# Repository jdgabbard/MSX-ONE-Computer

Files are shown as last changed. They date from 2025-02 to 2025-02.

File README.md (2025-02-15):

# MSX-ONE Computer

A small, easy to build MSX1 compatible computer.<br>

***See Build Notes file for special instructions!***

Designed as a cheap, and easy to build, MSX1 computer for the US Vintage Computer enthusiast.

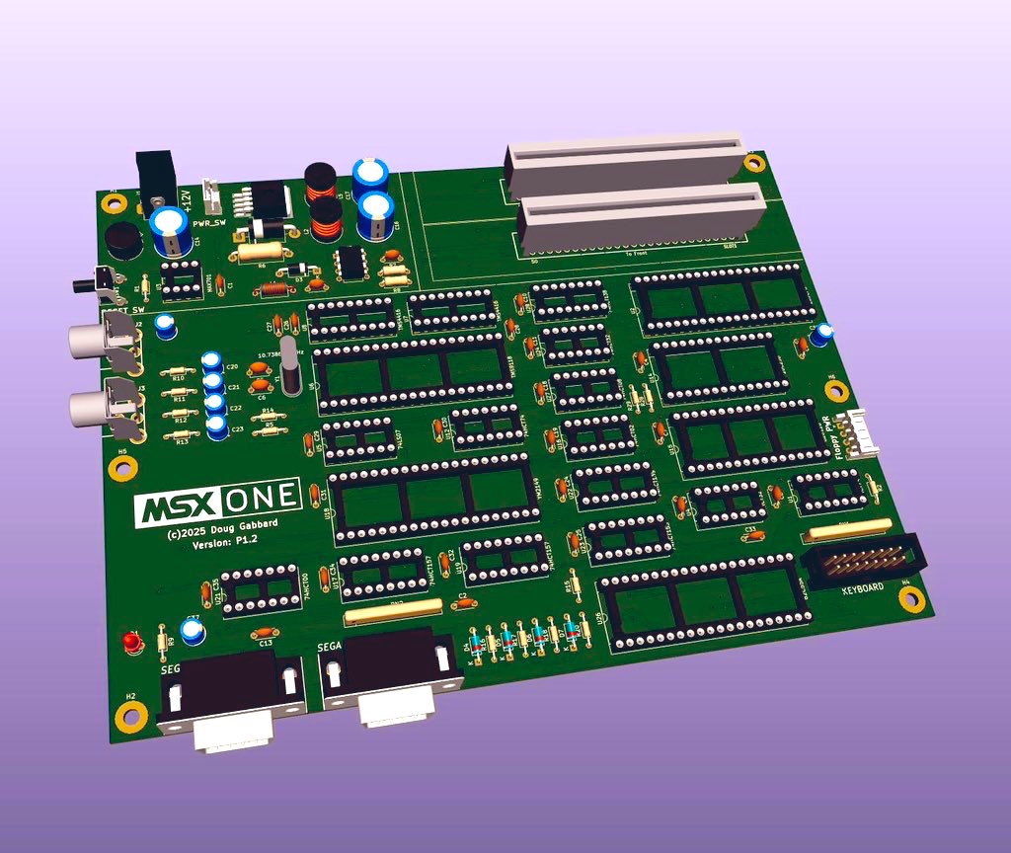
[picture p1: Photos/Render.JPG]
MSXONE


**Features include:**<br><br>
-Small Footprint:
     -Mainboard size: 200mm x 150mm
     -Keyboard size: 200mm x 95mm
-Power-On Reset Supervisor Circuit providing automatic 200ms Reset.
-Flexible power input handles +12v DC to +12v AC power supplies.<br>
-Implements +12v/-12v rails, so Audio Cartridges work correctly.<br>
-2x Sega Gamepad compatible ports, since finding MSX controllers in the US is all but impossible.<br>
-TMS9118 Low Cost alternative does away with numerous DRAM chips, or finicky SRAM circuits, using just two 4bit DRAMs.<br>
-Two Primary Slots available to the user.<br>
-Construction consisting of off the shelf TTL logic, without the need for any programable logic, SPLDs or FPGAs to worry about programming.<br>
-A small form factor, consisting of a PCB approximately the same size as a ZX Spectrum: 200mm x 150mm<br>
-A stackable keyboard (Omega Home Computer Compatible) using cheap tactile switches with an optional cover for aesthetics.<br><br>

**Inspiration**
This computer was heavily inspired by, and borrowing from, both Sergey Kiselev's Omega Home Computer, and the JFF Computer (https://github.com/konkotgit/JFF), as well as the Casio MX-10.<br><br>

I desired a MSX without all the fluff, but with the modularity that the Omega Computer affords.  I wanted a simplified circuit, but with nice options such as power regulation, options for a mechanical power switch, and +12v/-12v rails.  The MSX-ONE gives the casual MSX user just the basics to have a functional yet flexible machine for playing MSX1 games.  And it does this without the need for programmable logic.  The design uses all off the shelf TTL compatible parts, which are still in current production.<br><br>

**Specifications:**<br>
-TMS9118 VDP with 16k DRAM (2x4bit DRAMS)<br>
-32k EEPROM in SLOT0 (BIOS with International Keyboard, Mapper Initializer & BASIC 1.0)<br>
-64K SRAM in SLOT3<br>
-Standard PSG<br>
-International Keyboard<br>
-No Printer Port<br>
-No Cassette Interface<br>
-No Disk Drive<br>
-No Fluff<br>

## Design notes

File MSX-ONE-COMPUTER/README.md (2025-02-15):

# MSX-ONE Mainboard

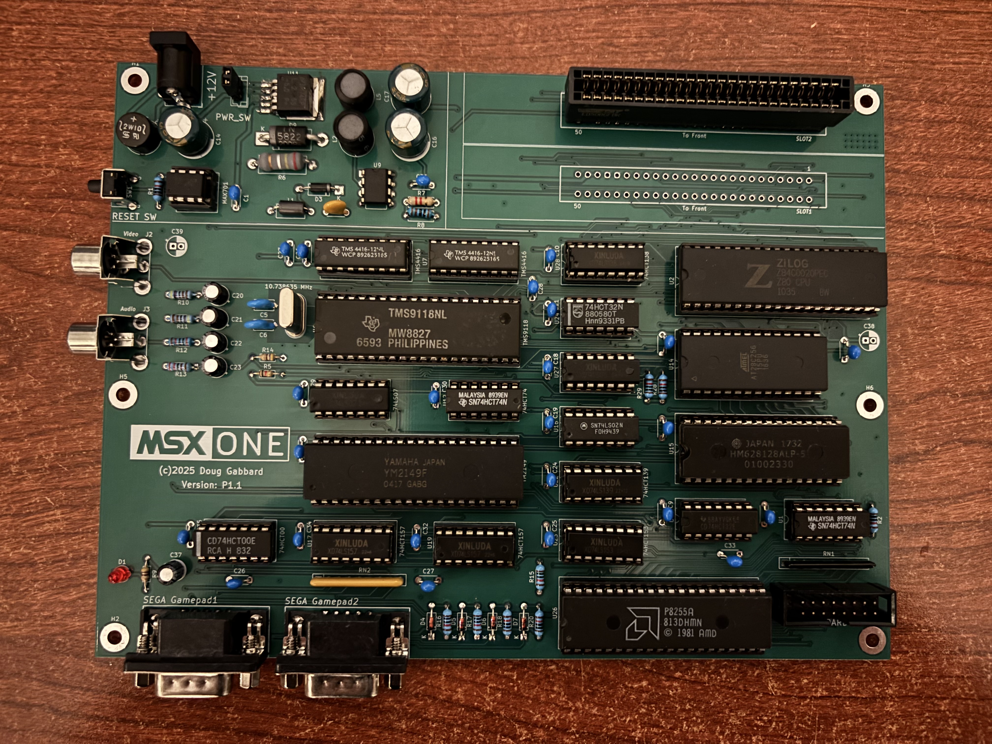
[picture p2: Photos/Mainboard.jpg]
Mainboard


Currently, v1.0 of the Mainboard is untested.  Three insignificant changes were made to the mainboard from version P1.1: the addition of a loading resistor on the -12v circuit, addition of a power connector for external floppy support, and a slight change to page select logic (should have no impact in function).  However, with that in mind, it is at this time untested.  Use of Prototype P1.1 version of the main board is preferable, as it is tested and functional at this time.  This will be changed as soon as I have a chance to order new boards and properly test them, in a few weeks.

#NOTE:
MAX701 has not been used in this circuit, due to sourcing issues.  I have opted to myself use a ATTINY85 with a firmware to automatically reset the system on boot and during reset.

BOM is being developed, along with a list of Digikey and Mouser part numbers.  Stay tuned...

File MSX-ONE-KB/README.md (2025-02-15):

# MSX-ONE Keyboard

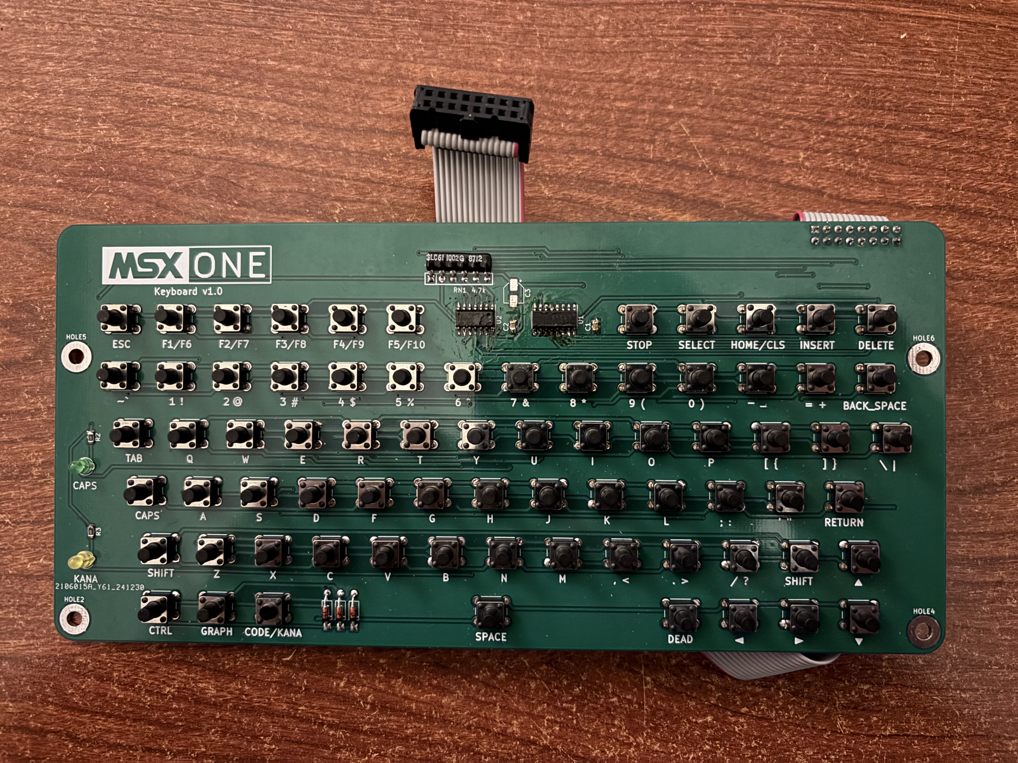
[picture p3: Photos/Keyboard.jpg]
Keyboard


The keyboard circuit is completely working, and stands at vesion 1.0

I will likely add a different board layout using standard 1/4w resistors for the LEDs.

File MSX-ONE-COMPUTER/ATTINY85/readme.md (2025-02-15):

#ATTINY85 Substitute for MAX701

Here are the fuse settings for the ATTINY85, use the Binary supplied in this folder, which provides a time delayed reset of the system during boot, and when reset is pressed.

Low Fuse: E2
High Fuse: D7
Extended Fuse: FF
Lock Bit: FF

ATTINY85 is set to 8mhz internal clock without a lock bit.

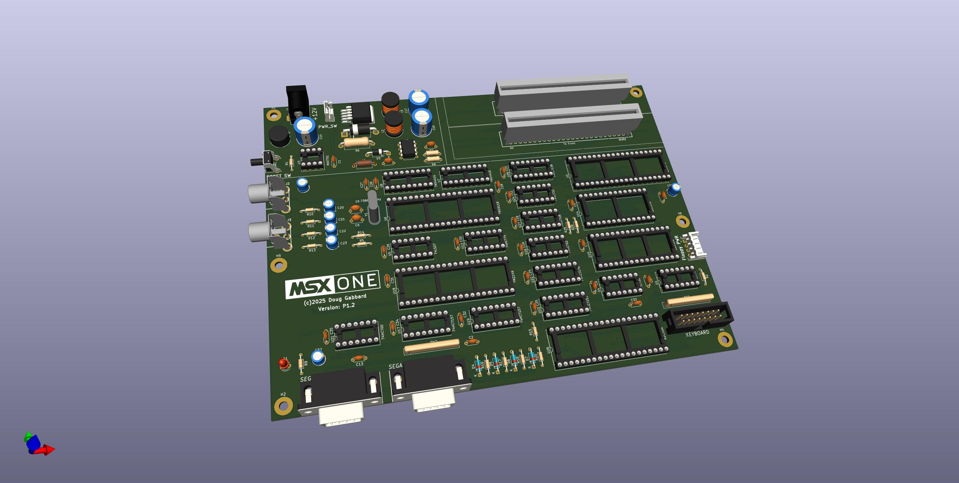
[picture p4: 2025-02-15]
MSX-ONE-COMPUTER/Kicad/MSX-ONE.jpg

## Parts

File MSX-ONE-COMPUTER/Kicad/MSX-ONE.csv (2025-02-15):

Source: | C:\Users\jdgab\Documents\KiCad\MSX-ONE\MSX-ONE-COMPUTER\Kicad\MSX-ONE.kicad_sch
Date: | 1/27/2025 6:11:55 PM
Tool: | Eeschema (6.0.7)
Generator: | C:\Program Files\KiCad\6.0\bin\scripting\plugins/bom_csv_grouped_by_value.py
Component Count: | 110
Individual Components:
Item | Qty | Reference(s) | Value | LibPart | Footprint | Datasheet
 |  | C1 | 100nF | Device:C | Capacitor_THT:C_Disc_D4.3mm_W1.9mm_P5.00mm | ~
 |  | C2 | 100nF | Device:C | Capacitor_THT:C_Disc_D4.3mm_W1.9mm_P5.00mm | ~
 |  | C3 | 100nF | Device:C | Capacitor_THT:C_Disc_D4.3mm_W1.9mm_P5.00mm | ~
 |  | C4 | 100nF | Device:C | Capacitor_THT:C_Disc_D4.3mm_W1.9mm_P5.00mm | ~
 |  | C5 | 27pF | Device:C | Capacitor_THT:C_Disc_D4.7mm_W2.5mm_P5.00mm | ~
 |  | C6 | 27pF | Device:C | Capacitor_THT:C_Disc_D4.7mm_W2.5mm_P5.00mm | ~
 |  | C7 | 100nF | Device:C | Capacitor_THT:C_Disc_D4.3mm_W1.9mm_P5.00mm | ~
 |  | C8 | 100nF | Device:C | Capacitor_THT:C_Disc_D4.3mm_W1.9mm_P5.00mm | ~
 |  | C9 | 100nF | Device:C | Capacitor_THT:C_Disc_D4.3mm_W1.9mm_P5.00mm | ~
 |  | C10 | 100nF | Device:C | Capacitor_THT:C_Disc_D4.3mm_W1.9mm_P5.00mm | ~
 |  | C11 | 100nF | Device:C | Capacitor_THT:C_Disc_D4.3mm_W1.9mm_P5.00mm | ~
 |  | C12 | 1.5nF | Device:C | Capacitor_THT:C_Disc_D4.3mm_W1.9mm_P5.00mm | ~
 |  | C14 | 220uF | Device:C_Polarized_Small | Capacitor_THT:CP_Radial_D10.0mm_P5.00mm | ~
 |  | C16 | 470uF | Device:C_Polarized | Capacitor_THT:CP_Radial_D10.0mm_P5.00mm | ~
 |  | C17 | 470uF | Device:C_Polarized | Capacitor_THT:CP_Radial_D10.0mm_P5.00mm | ~
 |  | C18 | 100nF | Device:C | Capacitor_THT:C_Disc_D4.3mm_W1.9mm_P5.00mm | ~
 |  | C19 | 100nF | Device:C | Capacitor_THT:C_Disc_D4.3mm_W1.9mm_P5.00mm | ~
 |  | C20 | 10uF | Device:C_Polarized_Small | Capacitor_THT:CP_Radial_D5.0mm_P2.50mm | ~
 |  | C21 | 10uF | Device:C_Polarized_Small | Capacitor_THT:CP_Radial_D5.0mm_P2.50mm | ~
 |  | C22 | 10uF | Device:C_Polarized_Small | Capacitor_THT:CP_Radial_D5.0mm_P2.50mm | ~
 |  | C23 | 10uF | Device:C_Polarized_Small | Capacitor_THT:CP_Radial_D5.0mm_P2.50mm | ~
 |  | C24 | 100nF | Device:C | Capacitor_THT:C_Disc_D4.3mm_W1.9mm_P5.00mm | ~
 |  | C25 | 100nF | Device:C | Capacitor_THT:C_Disc_D4.3mm_W1.9mm_P5.00mm | ~
 |  | C26 | 100nF | Device:C | Capacitor_THT:C_Disc_D4.3mm_W1.9mm_P5.00mm | ~
 |  | C27 | 100nF | Device:C | Capacitor_THT:C_Disc_D4.3mm_W1.9mm_P5.00mm | ~
 |  | C28 | 100nF | Device:C | Capacitor_THT:C_Disc_D4.3mm_W1.9mm_P5.00mm | ~
 |  | C29 | 100nF | Device:C | Capacitor_THT:C_Disc_D4.3mm_W1.9mm_P5.00mm | ~
 |  | C30 | 100nF | Device:C | Capacitor_THT:C_Disc_D4.3mm_W1.9mm_P5.00mm | ~
 |  | C31 | 100nF | Device:C | Capacitor_THT:C_Disc_D4.3mm_W1.9mm_P5.00mm | ~
 |  | C32 | 100nF | Device:C | Capacitor_THT:C_Disc_D4.3mm_W1.9mm_P5.00mm | ~
 |  | C33 | 100nF | Device:C | Capacitor_THT:C_Disc_D4.3mm_W1.9mm_P5.00mm | ~
 |  | C34 | 100nF | Device:C | Capacitor_THT:C_Disc_D4.3mm_W1.9mm_P5.00mm | ~
 |  | C35 | 100nF | Device:C | Capacitor_THT:C_Disc_D4.3mm_W1.9mm_P5.00mm | ~
 |  | C36 | 100nF | Device:C | Capacitor_THT:C_Disc_D4.3mm_W1.9mm_P5.00mm | ~
 |  | C37 | 10uF | Device:C_Polarized_Small_US | Capacitor_THT:CP_Radial_D5.0mm_P2.00mm | ~
 |  | C38 | 10uF | Device:C_Polarized_Small_US | Capacitor_THT:CP_Radial_D5.0mm_P2.00mm | ~
 |  | C39 | 10uF | Device:C_Polarized_Small_US | Capacitor_THT:CP_Radial_D5.0mm_P2.00mm | ~
 |  | D1 | LED | Device:LED | LED_THT:LED_D3.0mm | ~
 |  | D2 | 2W10 | Diode_Bridge:B40R | Diode_THT:Diode_Bridge_Round_D9.0mm | https://diotec.com/tl_files/diotec/files/pdf/datasheets/b40r.pdf
 |  | D3 | 1N5819 | Diode:1N5819 | Diode_THT:D_DO-41_SOD81_P10.16mm_Horizontal | http://www.vishay.com/docs/88525/1n5817.pdf
 |  | D4 | 1N4148 | Diode:1N4148 | Diode_THT:D_DO-35_SOD27_P7.62mm_Horizontal | https://assets.nexperia.com/documents/data-sheet/1N4148_1N4448.pdf
 |  | D5 | 1N4148 | Diode:1N4148 | Diode_THT:D_DO-35_SOD27_P7.62mm_Horizontal | https://assets.nexperia.com/documents/data-sheet/1N4148_1N4448.pdf
 |  | D6 | 1N4148 | Diode:1N4148 | Diode_THT:D_DO-35_SOD27_P7.62mm_Horizontal | https://assets.nexperia.com/documents/data-sheet/1N4148_1N4448.pdf
 |  | D7 | 1N4148 | Diode:1N4148 | Diode_THT:D_DO-35_SOD27_P7.62mm_Horizontal | https://assets.nexperia.com/documents/data-sheet/1N4148_1N4448.pdf
 |  | D9 | 1N5822 | Diode:1N5822 | Diode_THT:D_DO-201AD_P15.24mm_Horizontal | http://www.vishay.com/docs/88526/1n5820.pdf
 |  | H1 | Hole | Mechanical:MountingHole_Pad | MountingHole:MountingHole_3.5mm_Pad | ~
 |  | H2 | Hole | Mechanical:MountingHole_Pad | MountingHole:MountingHole_3.5mm_Pad | ~
 |  | H3 | Hole | Mechanical:MountingHole_Pad | MountingHole:MountingHole_3.5mm_Pad | ~
 |  | H4 | Hole | Mechanical:MountingHole_Pad | MountingHole:MountingHole_3.5mm_Pad | ~
 |  | H5 | Hole | Mechanical:MountingHole_Pad | MountingHole:MountingHole_3.5mm_Pad | ~
 |  | H6 | Hole | Mechanical:MountingHole_Pad | MountingHole:MountingHole_3.5mm_Pad | ~
 |  | J1 | +12V | Connector:Barrel_Jack_Switch | Connector_BarrelJack:BarrelJack_Horizontal | ~
 |  | J2 | Video | Connector:Conn_Coaxial | JfF-Library:Conn_RCA_Right | ~
 |  | J3 | Audio | Connector:Conn_Coaxial | JfF-Library:Conn_RCA_Right | ~
 |  | J4 | SEGA Gamepad1 | Connector:DB9_Male | JfF-Library:Conn_Dsub_DE9M | ~
 |  | J5 | SEGA Gamepad2 | Connector:DB9_Male | JfF-Library:Conn_Dsub_DE9M | ~
 |  | J6 | SLOT1 | Connector_Generic:Conn_02x25_Odd_Even | JfF-Library:Conn_Edge_50P | ~
 |  | J7 | SLOT2 | Connector_Generic:Conn_02x25_Odd_Even | JfF-Library:Conn_Edge_50P | ~
 |  | J9 | KEYBOARD | Connector_Generic:Conn_02x08_Odd_Even | Connector_PinHeader_2.54mm:PinHeader_2x08_P2.54mm_Vertical | ~
 |  | L1 | 1uH | Device:L | Inductor_THT:L_Axial_L7.0mm_D3.3mm_P10.16mm_Horizontal_Fastron_MICC | ~
 |  | L2 | 88uH | Device:L | Inductor_THT:L_Radial_D8.7mm_P5.00mm_Fastron_07HCP | ~
 |  | L5 | 68uH | Device:L | Inductor_THT:L_Radial_D8.7mm_P5.00mm_Fastron_07HCP | ~
 |  | R1 | 1K | Device:R | Resistor_THT:R_Axial_DIN0204_L3.6mm_D1.6mm_P7.62mm_Horizontal | ~
 |  | R2 | 10K | Device:R | Resistor_THT:R_Axial_DIN0204_L3.6mm_D1.6mm_P7.62mm_Horizontal | ~
 |  | R5 | 1K | Device:R | Resistor_THT:R_Axial_DIN0204_L3.6mm_D1.6mm_P7.62mm_Horizontal | ~
 |  | R6 | 0.24R | Device:R_Small_US | Resistor_THT:R_Axial_DIN0414_L11.9mm_D4.5mm_P15.24mm_Horizontal | ~
 |  | R7 | 10k | Device:R_US | Resistor_THT:R_Axial_DIN0207_L6.3mm_D2.5mm_P7.62mm_Horizontal | ~
 |  | R8 | 1k | Device:R_US | Resistor_THT:R_Axial_DIN0207_L6.3mm_D2.5mm_P7.62mm_Horizontal | ~
 |  | R9 | 470R | Device:R | Resistor_THT:R_Axial_DIN0204_L3.6mm_D1.6mm_P7.62mm_Horizontal | ~
 |  | R10 | 4K7 | Device:R | Resistor_THT:R_Axial_DIN0204_L3.6mm_D1.6mm_P7.62mm_Horizontal | ~
 |  | R11 | 4K7 | Device:R | Resistor_THT:R_Axial_DIN0204_L3.6mm_D1.6mm_P7.62mm_Horizontal | ~
 |  | R12 | 20K | Device:R | Resistor_THT:R_Axial_DIN0204_L3.6mm_D1.6mm_P7.62mm_Horizontal | ~
 |  | R13 | 2K2 | Device:R | Resistor_THT:R_Axial_DIN0204_L3.6mm_D1.6mm_P7.62mm_Horizontal | ~
 |  | R14 | 470R | Device:R | Resistor_THT:R_Axial_DIN0204_L3.6mm_D1.6mm_P7.62mm_Horizontal | ~
 |  | R15 | 10K | Device:R | Resistor_THT:R_Axial_DIN0204_L3.6mm_D1.6mm_P7.62mm_Horizontal | ~
 |  | R16 | 10K | Device:R | Resistor_THT:R_Axial_DIN0204_L3.6mm_D1.6mm_P7.62mm_Horizontal | ~
 |  | R17 | 10K | Device:R | Resistor_THT:R_Axial_DIN0204_L3.6mm_D1.6mm_P7.62mm_Horizontal | ~
 |  | R18 | 10K | Device:R | Resistor_THT:R_Axial_DIN0204_L3.6mm_D1.6mm_P7.62mm_Horizontal | ~
 |  | R20 | 10K | Device:R | Resistor_THT:R_Axial_DIN0204_L3.6mm_D1.6mm_P7.62mm_Horizontal | ~
 |  | R28 | 10K | Device:R | Resistor_THT:R_Axial_DIN0204_L3.6mm_D1.6mm_P7.62mm_Horizontal | ~
 |  | R29 | 10K | Device:R | Resistor_THT:R_Axial_DIN0204_L3.6mm_D1.6mm_P7.62mm_Horizontal | ~
 |  | RN1 | 4.7K | Device:R_Network08 | Resistor_THT:R_Array_SIP9 | http://www.vishay.com/docs/31509/csc.pdf
 |  | RN2 | 10K | Device:R_Network08 | Resistor_THT:R_Array_SIP9 | http://www.vishay.com/docs/31509/csc.pdf
 |  | SW1 | RESET SW | Switch:SW_Push | Button_Switch_THT:SW_Tactile_SPST_Angled_PTS645Vx83-2LFS | ~
 |  | SW2 | PWR_SW | Jumper:Jumper_2_Open | Connector_JST:JST_EH_B2B-EH-A_1x02_P2.50mm_Vertical | ~
 |  | U1 | 74HCT74 | 74xx:74LS74 | Package_DIP:DIP-14_W7.62mm_Socket | 74xx/74hc_hct74.pdf
 |  | U2 | Z80CPU | CPU:Z80CPU | Package_DIP:DIP-40_W15.24mm_Socket | www.zilog.com/manage_directlink.php?filepath=docs/z80/um0080
 |  | U3 | MAX701 | Power_Supervisor:MAX701 | Package_DIP:DIP-8_W7.62mm_Socket
 |  | U4 | 74HCT32 | 74xx:74LS32 | Package_DIP:DIP-14_W7.62mm_Socket | http://www.ti.com/lit/gpn/sn74LS32
 |  | U5 | 74LS07 | 74xx:74LS07 | Package_DIP:DIP-14_W7.62mm_Socket | www.ti.com/lit/ds/symlink/sn74ls07.pdf
 |  | U6 | TMS9118 | v9938:TMS9118 | Package_DIP:DIP-40_W15.24mm_Socket
 |  | U7 | TMS4416 | v9938:TMS4416 | Package_DIP:DIP-18_W7.62mm_Socket
 |  | U8 | TMS4416 | v9938:TMS4416 | Package_DIP:DIP-18_W7.62mm_Socket
 |  | U9 | MC34063AP | Regulator_Switching:MC34063AP | Package_DIP:DIP-8_W7.62mm | http://www.onsemi.com/pub_link/Collateral/MC34063A-D.PDF
 |  | U11 | LM2596S-5 | Regulator_Switching:LM2596S-5 | Package_TO_SOT_SMD:TO-263-5_TabPin3 | http://www.ti.com/lit/ds/symlink/lm2596.pdf
 |  | U12 | 74HCT74 | 74xx:74LS74 | Package_DIP:DIP-14_W7.62mm_Socket | 74xx/74hc_hct74.pdf
 |  | U14 | 28C256 | Memory_EEPROM:28C256 | Package_DIP:DIP-28_W15.24mm_Socket | http://ww1.microchip.com/downloads/en/DeviceDoc/doc0006.pdf
 |  | U15 | 628128 | Memory_RAM:628128_DIP32_SSOP32 | Package_DIP:DIP-32_W15.24mm_Socket | http://www.futurlec.com/Datasheet/Memory/628128.pdf
 |  | U16 | 74HCT02 | 74xx:74LS02 | Package_DIP:DIP-14_W7.62mm_Socket | http://www.ti.com/lit/gpn/sn74ls02
 |  | U17 | 74HCT157 | 74xx:74LS157 | Package_DIP:DIP-16_W7.62mm_Socket | http://www.ti.com/lit/gpn/sn74LS157
 |  | U18 | YM2149 | Audio:YM2149 | Package_DIP:DIP-40_W15.24mm_Socket | http://www.ym2149.com/ym2149.pdf
 |  | U19 | 74HCT157 | 74xx:74LS157 | Package_DIP:DIP-16_W7.62mm_Socket | http://www.ti.com/lit/gpn/sn74LS157
 |  | U21 | 74HCT00 | 74xx:74LS00 | Package_DIP:DIP-14_W7.62mm_Socket | http://www.ti.com/lit/gpn/sn74ls00
 |  | U22 | 74HCT139 | 74xx:74LS139 | Package_DIP:DIP-16_W7.62mm_Socket | http://www.ti.com/lit/ds/symlink/sn74ls139a.pdf
 |  | U23 | 74HCT153 | 74xx:74LS153 | Package_DIP:DIP-16_W7.62mm_Socket | http://www.ti.com/lit/gpn/sn74LS153
 |  | U24 | 74HCT32 | 74xx:74LS32 | Package_DIP:DIP-14_W7.62mm_Socket | http://www.ti.com/lit/gpn/sn74LS32
 |  | U26 | 82C55A | Interface:8255A | Package_DIP:DIP-40_W15.24mm_Socket | http://aturing.umcs.maine.edu/~meadow/courses/cos335/Intel8255A.pdf
 |  | U27 | 74HCT08 | 74xx:74LS08 | Package_DIP:DIP-14_W7.62mm_Socket | http://www.ti.com/lit/gpn/sn74LS08
 |  | U28 | 74HCT138 | 74xx:74LS138 | Package_DIP:DIP-16_W7.62mm_Socket | http://www.ti.com/lit/gpn/sn74LS138
 |  | Y1 | 10.738635 MHz | Device:Crystal | Crystal:Crystal_HC49-U_Vertical | ~
Collated Components:
Item | Qty | Reference(s) | Value | LibPart | Footprint | Datasheet
1 | 24 | C1, C2, C3, C4, C7, C8, C9, C10, C11, C18, C19, C24, C25, C26, C27, C28, C29, C30, C31, C32, C33, C34, C35, C36 | 100nF | Device:C | Capacitor_THT:C_Disc_D4.3mm_W1.9mm_P5.00mm | ~
2 | 2 | C5, C6 | 27pF | Device:C | Capacitor_THT:C_Disc_D4.7mm_W2.5mm_P5.00mm | ~
3 | 1 | C12 | 1.5nF | Device:C | Capacitor_THT:C_Disc_D4.3mm_W1.9mm_P5.00mm | ~
4 | 1 | C14 | 220uF | Device:C_Polarized_Small | Capacitor_THT:CP_Radial_D10.0mm_P5.00mm | ~
5 | 2 | C16, C17 | 470uF | Device:C_Polarized | Capacitor_THT:CP_Radial_D10.0mm_P5.00mm | ~
6 | 4 | C20, C21, C22, C23 | 10uF | Device:C_Polarized_Small | Capacitor_THT:CP_Radial_D5.0mm_P2.50mm | ~
7 | 3 | C37, C38, C39 | 10uF | Device:C_Polarized_Small_US | Capacitor_THT:CP_Radial_D5.0mm_P2.00mm | ~
8 | 1 | D1 | LED | Device:LED | LED_THT:LED_D3.0mm | ~
9 | 1 | D2 | 2W10 | Diode_Bridge:B40R | Diode_THT:Diode_Bridge_Round_D9.0mm | https://diotec.com/tl_files/diotec/files/pdf/datasheets/b40r.pdf
10 | 1 | D3 | 1N5819 | Diode:1N5819 | Diode_THT:D_DO-41_SOD81_P10.16mm_Horizontal | http://www.vishay.com/docs/88525/1n5817.pdf
11 | 4 | D4, D5, D6, D7 | 1N4148 | Diode:1N4148 | Diode_THT:D_DO-35_SOD27_P7.62mm_Horizontal | https://assets.nexperia.com/documents/data-sheet/1N4148_1N4448.pdf
12 | 1 | D9 | 1N5822 | Diode:1N5822 | Diode_THT:D_DO-201AD_P15.24mm_Horizontal | http://www.vishay.com/docs/88526/1n5820.pdf
13 | 6 | H1, H2, H3, H4, H5, H6 | Hole | Mechanical:MountingHole_Pad | MountingHole:MountingHole_3.5mm_Pad | ~
14 | 1 | J1 | +12V | Connector:Barrel_Jack_Switch | Connector_BarrelJack:BarrelJack_Horizontal | ~
15 | 1 | J2 | Video | Connector:Conn_Coaxial | JfF-Library:Conn_RCA_Right | ~
16 | 1 | J3 | Audio | Connector:Conn_Coaxial | JfF-Library:Conn_RCA_Right | ~
17 | 1 | J4 | SEGA Gamepad1 | Connector:DB9_Male | JfF-Library:Conn_Dsub_DE9M | ~
18 | 1 | J5 | SEGA Gamepad2 | Connector:DB9_Male | JfF-Library:Conn_Dsub_DE9M | ~
19 | 1 | J6 | SLOT1 | Connector_Generic:Conn_02x25_Odd_Even | JfF-Library:Conn_Edge_50P | ~
20 | 1 | J7 | SLOT2 | Connector_Generic:Conn_02x25_Odd_Even | JfF-Library:Conn_Edge_50P | ~
21 | 1 | J9 | KEYBOARD | Connector_Generic:Conn_02x08_Odd_Even | Connector_PinHeader_2.54mm:PinHeader_2x08_P2.54mm_Vertical | ~
22 | 1 | L1 | 1uH | Device:L | Inductor_THT:L_Axial_L7.0mm_D3.3mm_P10.16mm_Horizontal_Fastron_MICC | ~
23 | 1 | L2 | 88uH | Device:L | Inductor_THT:L_Radial_D8.7mm_P5.00mm_Fastron_07HCP | ~
24 | 1 | L5 | 68uH | Device:L | Inductor_THT:L_Radial_D8.7mm_P5.00mm_Fastron_07HCP | ~
25 | 2 | R1, R5 | 1K | Device:R | Resistor_THT:R_Axial_DIN0204_L3.6mm_D1.6mm_P7.62mm_Horizontal | ~
26 | 8 | R2, R15, R16, R17, R18, R20, R28, R29 | 10K | Device:R | Resistor_THT:R_Axial_DIN0204_L3.6mm_D1.6mm_P7.62mm_Horizontal | ~
27 | 1 | R6 | 0.24R | Device:R_Small_US | Resistor_THT:R_Axial_DIN0414_L11.9mm_D4.5mm_P15.24mm_Horizontal | ~
28 | 1 | R7 | 10k | Device:R_US | Resistor_THT:R_Axial_DIN0207_L6.3mm_D2.5mm_P7.62mm_Horizontal | ~
29 | 1 | R8 | 1k | Device:R_US | Resistor_THT:R_Axial_DIN0207_L6.3mm_D2.5mm_P7.62mm_Horizontal | ~
30 | 2 | R9, R14 | 470R | Device:R | Resistor_THT:R_Axial_DIN0204_L3.6mm_D1.6mm_P7.62mm_Horizontal | ~
31 | 2 | R10, R11 | 4K7 | Device:R | Resistor_THT:R_Axial_DIN0204_L3.6mm_D1.6mm_P7.62mm_Horizontal | ~
32 | 1 | R12 | 20K | Device:R | Resistor_THT:R_Axial_DIN0204_L3.6mm_D1.6mm_P7.62mm_Horizontal | ~
33 | 1 | R13 | 2K2 | Device:R | Resistor_THT:R_Axial_DIN0204_L3.6mm_D1.6mm_P7.62mm_Horizontal | ~
34 | 1 | RN1 | 4.7K | Device:R_Network08 | Resistor_THT:R_Array_SIP9 | http://www.vishay.com/docs/31509/csc.pdf
35 | 1 | RN2 | 10K | Device:R_Network08 | Resistor_THT:R_Array_SIP9 | http://www.vishay.com/docs/31509/csc.pdf
36 | 1 | SW1 | RESET SW | Switch:SW_Push | Button_Switch_THT:SW_Tactile_SPST_Angled_PTS645Vx83-2LFS | ~
37 | 1 | SW2 | PWR_SW | Jumper:Jumper_2_Open | Connector_JST:JST_EH_B2B-EH-A_1x02_P2.50mm_Vertical | ~
38 | 2 | U1, U12 | 74HCT74 | 74xx:74LS74 | Package_DIP:DIP-14_W7.62mm_Socket | 74xx/74hc_hct74.pdf
39 | 1 | U2 | Z80CPU | CPU:Z80CPU | Package_DIP:DIP-40_W15.24mm_Socket | www.zilog.com/manage_directlink.php?filepath=docs/z80/um0080
40 | 1 | U3 | MAX701 | Power_Supervisor:MAX701 | Package_DIP:DIP-8_W7.62mm_Socket
41 | 2 | U4, U24 | 74HCT32 | 74xx:74LS32 | Package_DIP:DIP-14_W7.62mm_Socket | http://www.ti.com/lit/gpn/sn74LS32
42 | 1 | U5 | 74LS07 | 74xx:74LS07 | Package_DIP:DIP-14_W7.62mm_Socket | www.ti.com/lit/ds/symlink/sn74ls07.pdf
43 | 1 | U6 | TMS9118 | v9938:TMS9118 | Package_DIP:DIP-40_W15.24mm_Socket
44 | 2 | U7, U8 | TMS4416 | v9938:TMS4416 | Package_DIP:DIP-18_W7.62mm_Socket
45 | 1 | U9 | MC34063AP | Regulator_Switching:MC34063AP | Package_DIP:DIP-8_W7.62mm | http://www.onsemi.com/pub_link/Collateral/MC34063A-D.PDF
46 | 1 | U11 | LM2596S-5 | Regulator_Switching:LM2596S-5 | Package_TO_SOT_SMD:TO-263-5_TabPin3 | http://www.ti.com/lit/ds/symlink/lm2596.pdf
47 | 1 | U14 | 28C256 | Memory_EEPROM:28C256 | Package_DIP:DIP-28_W15.24mm_Socket | http://ww1.microchip.com/downloads/en/DeviceDoc/doc0006.pdf
48 | 1 | U15 | 628128 | Memory_RAM:628128_DIP32_SSOP32 | Package_DIP:DIP-32_W15.24mm_Socket | http://www.futurlec.com/Datasheet/Memory/628128.pdf
49 | 1 | U16 | 74HCT02 | 74xx:74LS02 | Package_DIP:DIP-14_W7.62mm_Socket | http://www.ti.com/lit/gpn/sn74ls02
50 | 2 | U17, U19 | 74HCT157 | 74xx:74LS157 | Package_DIP:DIP-16_W7.62mm_Socket | http://www.ti.com/lit/gpn/sn74LS157
51 | 1 | U18 | YM2149 | Audio:YM2149 | Package_DIP:DIP-40_W15.24mm_Socket | http://www.ym2149.com/ym2149.pdf
52 | 1 | U21 | 74HCT00 | 74xx:74LS00 | Package_DIP:DIP-14_W7.62mm_Socket | http://www.ti.com/lit/gpn/sn74ls00
53 | 1 | U22 | 74HCT139 | 74xx:74LS139 | Package_DIP:DIP-16_W7.62mm_Socket | http://www.ti.com/lit/ds/symlink/sn74ls139a.pdf
54 | 1 | U23 | 74HCT153 | 74xx:74LS153 | Package_DIP:DIP-16_W7.62mm_Socket | http://www.ti.com/lit/gpn/sn74LS153
55 | 1 | U26 | 82C55A | Interface:8255A | Package_DIP:DIP-40_W15.24mm_Socket | http://aturing.umcs.maine.edu/~meadow/courses/cos335/Intel8255A.pdf
56 | 1 | U27 | 74HCT08 | 74xx:74LS08 | Package_DIP:DIP-14_W7.62mm_Socket | http://www.ti.com/lit/gpn/sn74LS08
57 | 1 | U28 | 74HCT138 | 74xx:74LS138 | Package_DIP:DIP-16_W7.62mm_Socket | http://www.ti.com/lit/gpn/sn74LS138
58 | 1 | Y1 | 10.738635 MHz | Device:Crystal | Crystal:Crystal_HC49-U_Vertical | ~

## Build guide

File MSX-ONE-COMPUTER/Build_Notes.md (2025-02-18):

**MSX-ONE BUILD NOTES**

Mainboard

I am still working on a BOM for the MSX-ONE Mainboard. However, in the meantime here are some items builders should note.

PCB version P1.1 in the Gerbs folder is the last tested version. However, this version has a small flaw. U9, the MC34063a buck converter IC used for the -12v rail needs to have pins 7 & 8 solder-jumpered together during the build process. Without this, the -12v rail will not be present, and the MC34063a will overheat and fail. In addition to this, I would suggest adding a 1-Watt 1K or 2K resistor between -12v and GND on the underside of the board. This helps to stabilize the -12v rail, resulting in less voltage ripple, as the MC34063a skips oscillation when -12v is reached. Adding this simple resistor helps prevent the skipped oscillation, making the voltage level more stable. This has been changed on the v1.0 PCB, though that PCB has not been tested at this time.

**BOM**
Name        | Description              | Part#                       | DigiKey                           | Mouser                             | Notes
------------|--------------------------|-----------------------------|-----------------------------------|------------------------------------|---------------------------
PCB         | MSX-ONE PCB              |                             |                                   |                                    | I use JLCPCB, Good Prices.
U1, U12	    | 74HCT74	               | SN74HCT74N                  | 296-1625-5-ND                     | 595-SN74HCT74N                     | Can use LS or HCT Technology
U2	        | Z80 Microprocessor       |                             |                                   |                                    | *Ebay or 2nd Hand Market
U3          | MAX701 or ATTiny85 (Binary Provided)| MAX701EPA+ or ATTINY85-20PU | MAX701EPA+-ND or ATTINY85-20PU-ND | 700-MAX701EPA or 556-ATTINY85-20PU | *Use ATTINY with LS Parts, it has more drive/sink current
U4, U24     | 74HCT32                  | SN74HCT32N                  | 296-1615-5-ND                     | 595-SN74HCT32N                     | Can use LS or HCT Technology
U5          | 74LS07                   | SN74LS07N                   | 296-14878-5-ND                    | 595-SN74LS07N                      | Only available in LS technology
U6          | TMS9118 VDP              |                             |                                   |                                    | *Ebay or 2nd Hand Market
U7, U8      | TMS4416 DRAM             |                             |                                   |                                    | *Ebay or 2nd Hand Market
U9          | MC34063A                 | MC34063ABN                  | 497-7412-5-ND                     | 511-MC34063ABN                     | A dinosaur, but effective
U11         | LM2596S-5.0              | LM2596S-5.0/NOPB            | LM2596S-5.0/NOPB-ND               | 926-LM2596S-5.0/NOPB               | The Only SMD Part
U14         | AT28C256 EEPROM          | AT28C256-15PU               | AT28C256-15PU                     | 556-AT28C25615PU                   | *Cheaper on Ebay or 2nd Hand
U15         | HM628128 SRAM            | SST39SF040-70-4C-PHE        | SST39SF040-70-4C-PHE-ND           | 804-39SF0407CPHE                   | *Ebay, but can use 39SF040/020
U16         | 74HCT02                  | SN74HCT02N                  | 296-8380-5-ND                     | 595-SN74HCT02N                     | Can use LS or HCT Technology
U17, U19    | 74HCT157                 | SN74HCT157N                 | SN74HCT157N                       | 595-SN74HCT157N                    | Can use LS or HCT Technology
U18         | YM2149 PSG               |  YM2149 or AY-3-8910        |                                   |                                    | *Ebay or 2nd Hand Market
U21         | 74HCT00                  | SN74HCT00N                  | 296-1603-5-ND                     | 595-SN74HCT00N                     | Can use LS or HCT Technology
U22         | 74HCT139                 | SN74HCT139N                 | 296-8390-5-ND                     | 595-SN74HCT139N                    | Can use LS or HCT Technology
U23         | 74HCT153                 | CD74HCT153E                 | 296-2094-5-ND                     | 595-CD74HCT153E                    | Can use LS or HCT Technology
U26         | 82C55A PPI               | i82C55A or CP82C55A-5Z      | CP82C55A-5Z-ND                    |968-CP82C55A-5Z                     | *Cheaper on Ebay or 2nd Hand
U27         | 74HCT08                  | SN74HCT08N                  | 296-1606-5-ND                     | 595-SN74HCT08N                     | Can use LS or HCT Technology
U28         | 74HCT138                 | SN74HCT138N                 | 296-1608-5-ND                     | 595-SN74HCT138N                    | Can use LS or HCT Technology
L1          | 1uH Ferrite Bead         | 2743005112                  | 1934-1416-1-ND                    | 623-2743005112                     | 
L2, L5      | 88uH Inductor            | AIUR-06-680K                | AIUR-06-680K-ND                   | 815-AIUR-06-680K                   | 
Y1          | 10.738635 MHz Crystal    | MP107-E                     | CTX1443-ND                        | 774-MP107-E                        | May be difficult to source
D1          | 3mm Red LED              | 732-5006-ND                 | 710-151031SS06000                 | 151031SS06000                      | 
D2          | 2W10 Bridge Rectifier    | 2W10                        | 4786-2W10GCT-ND                   | 625-2W10G-E4                       | 
D3          | 1N5819                   | 1N5819                      | 497-6610-1-ND                     | 511-1N5819                         | 
D4,D5,D6,D7 | 1N4148                   | 1N4148                      | 1N4148FS-ND                       | 512-1N4148                         | 
D9          | 1N5822                   | 1N5822                      | 497-14742-1-ND                    | 511-1N5822-TR                      | 
RN1, RN2    | 4.7kohm Resistor Array   | 4609X-101-472LF             | 4609X-101-472LF-ND                | 652-4609X-1LF-4.7K                 | 
R6          | 0.24ohm Resistor         | RR01JR24TB                  | A138235TB-ND                      | 279-RR01JR24TB                     | *Need to check physical size
R1-2,R15-18,R20,R28-29 | 1/8w 10Kohm Resistor | CF18JT10K0           | CF18JT10K0CT-ND                   | 708-CF18JT10K0                     | 
R3          | 1Kohm 1/2W Resistor      | CFR-50JB-52-1K              | 1.0KH-ND                          | 603-CFR-50JB-52-1K                 | *Need to check physical size
R8,R5       | 1/8w 1Kohm Resistor      | CF18JT1K00                  | CF18JT1K00CT-ND                   | 708-CF18JT1K00                     | 
R7          | 1/8w 8.2K Resistor       | CF18JT8K20                  | CF18JT8K20CT-ND                   | 603-CFR-12JR-52-8K2                | *May substitute 10k, but -12v will be incorrect voltage
R9,R14      | 1/8w 470ohm Resistor     | CF18JT470R                  | CF18JT470RCT-ND                   | 708-CF18JT470R                     | 
R10,R11     | 1/8w 4.7Kohm Resistor    | CF18JT4K70                  | CF18JT4K70CT-ND                   | 708-CF18JT4K70                     | 
R12         | 1/8w 20Kohm Resistor     | CF18JT20K0                  | CF18JT20K0CT-ND                   | 708-CF18JT20K0                     | 
R13         | 1/8w 2.2kohm Resistor    | CF18JT2K20                  | CF18JT2K20CT-ND                   | 708-CF18JT2K20                     | 
C14,C16,C17 | 470uF Electrol Capacitor | UVR1E471MPD                 | 493-1064-ND                       | 647-UVR1E471MPD                    | 
C20-23,C37-39| 10uF Electroly Capacitor| ECE-A1EKS100I               | 10-ECE-A1EKS100ICT-ND             | 667-ECE-A1EKS100I                  |
C5, C6      | 27pF Ceramic Capacitor   | RCE5C2A270J0M1H03A          | 490-7451-1-ND                     | 81-RCE5C2A270J0M1H3A               | 
C1-4,C7-11,C18-19,C24-36 | 100nF Ceramic Capacitor | FK28X7R1H104KN000| 445-FK28X7R1H104KN000-ND         | 810-FK28X7R1H104K                  | 
C12         | 470pF Ceramic Capacitor  | S471K29Y5PP63K5R            | 1286PH-ND                         | 594-S471K29Y5PP63K5R               | *Datasheet specifies 1.5nF, lots of noise with that value
SLOT1,SLOT2 | 50pin Card Edge          | 5530843-5                   | A31718-ND                         | 571-5530843-5                      | 
Gamepad1/2  | DB9 Male                 | L717SDE09P1ACH3R            | L717SDE09P1ACH3R-ND               | 523-L717SDE09P1ACH3R               | 
J2          | Yellow RCA               | RCJ-014                     | CP-1403-ND                        | 490-RCJ-014                        | 
J3          | White RCA                | RCJ-013                     | CP-1402-ND                        | 490-RCJ-013                        | 
J1          | DC Jack                  | KLDX-0202-A                 | 2092-KLDX-0202-A-ND               | 806-KLDX-0202-A                    | 
J9          | IDC 2x8P                 | 61201621621                 | 732-2095-ND                       | 710-61201621621                    | 
J8          | JST 4pin Right Angle     | S4B-XH-A-1                  | 455-S4B-XH-A-1-ND                 | 306-S4BXHA1LFSN                    | *Need to verify part compatibility
SW1         | Tactile SW Right Angle   | PTS645VK58-2 LFS            | CKN10965-ND                       | 611-PTS645VK582                    | *Need to verify part compatibility
PWR_SW      | JST 2pin Right Angle     | B2B-XH-A                    | 455-B2B-XH-A-ND                   | 306-B2BXHALFSNP                    |

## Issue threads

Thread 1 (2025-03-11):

PCB Error

JmanNZ, 2025-03-11:
Hi
I have a working MSXONE. Thank you. PCB version P1.1
One issue pin 30 of the 628128 is not connected. This caused a no boot error for me.
Adding a small wire link to 5V solved the issue.

Regards
John

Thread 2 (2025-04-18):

2nd PCB Error

JmanNZ, 2025-04-18:
Pin 8 of U23 is unconnected should be connected to gnd.

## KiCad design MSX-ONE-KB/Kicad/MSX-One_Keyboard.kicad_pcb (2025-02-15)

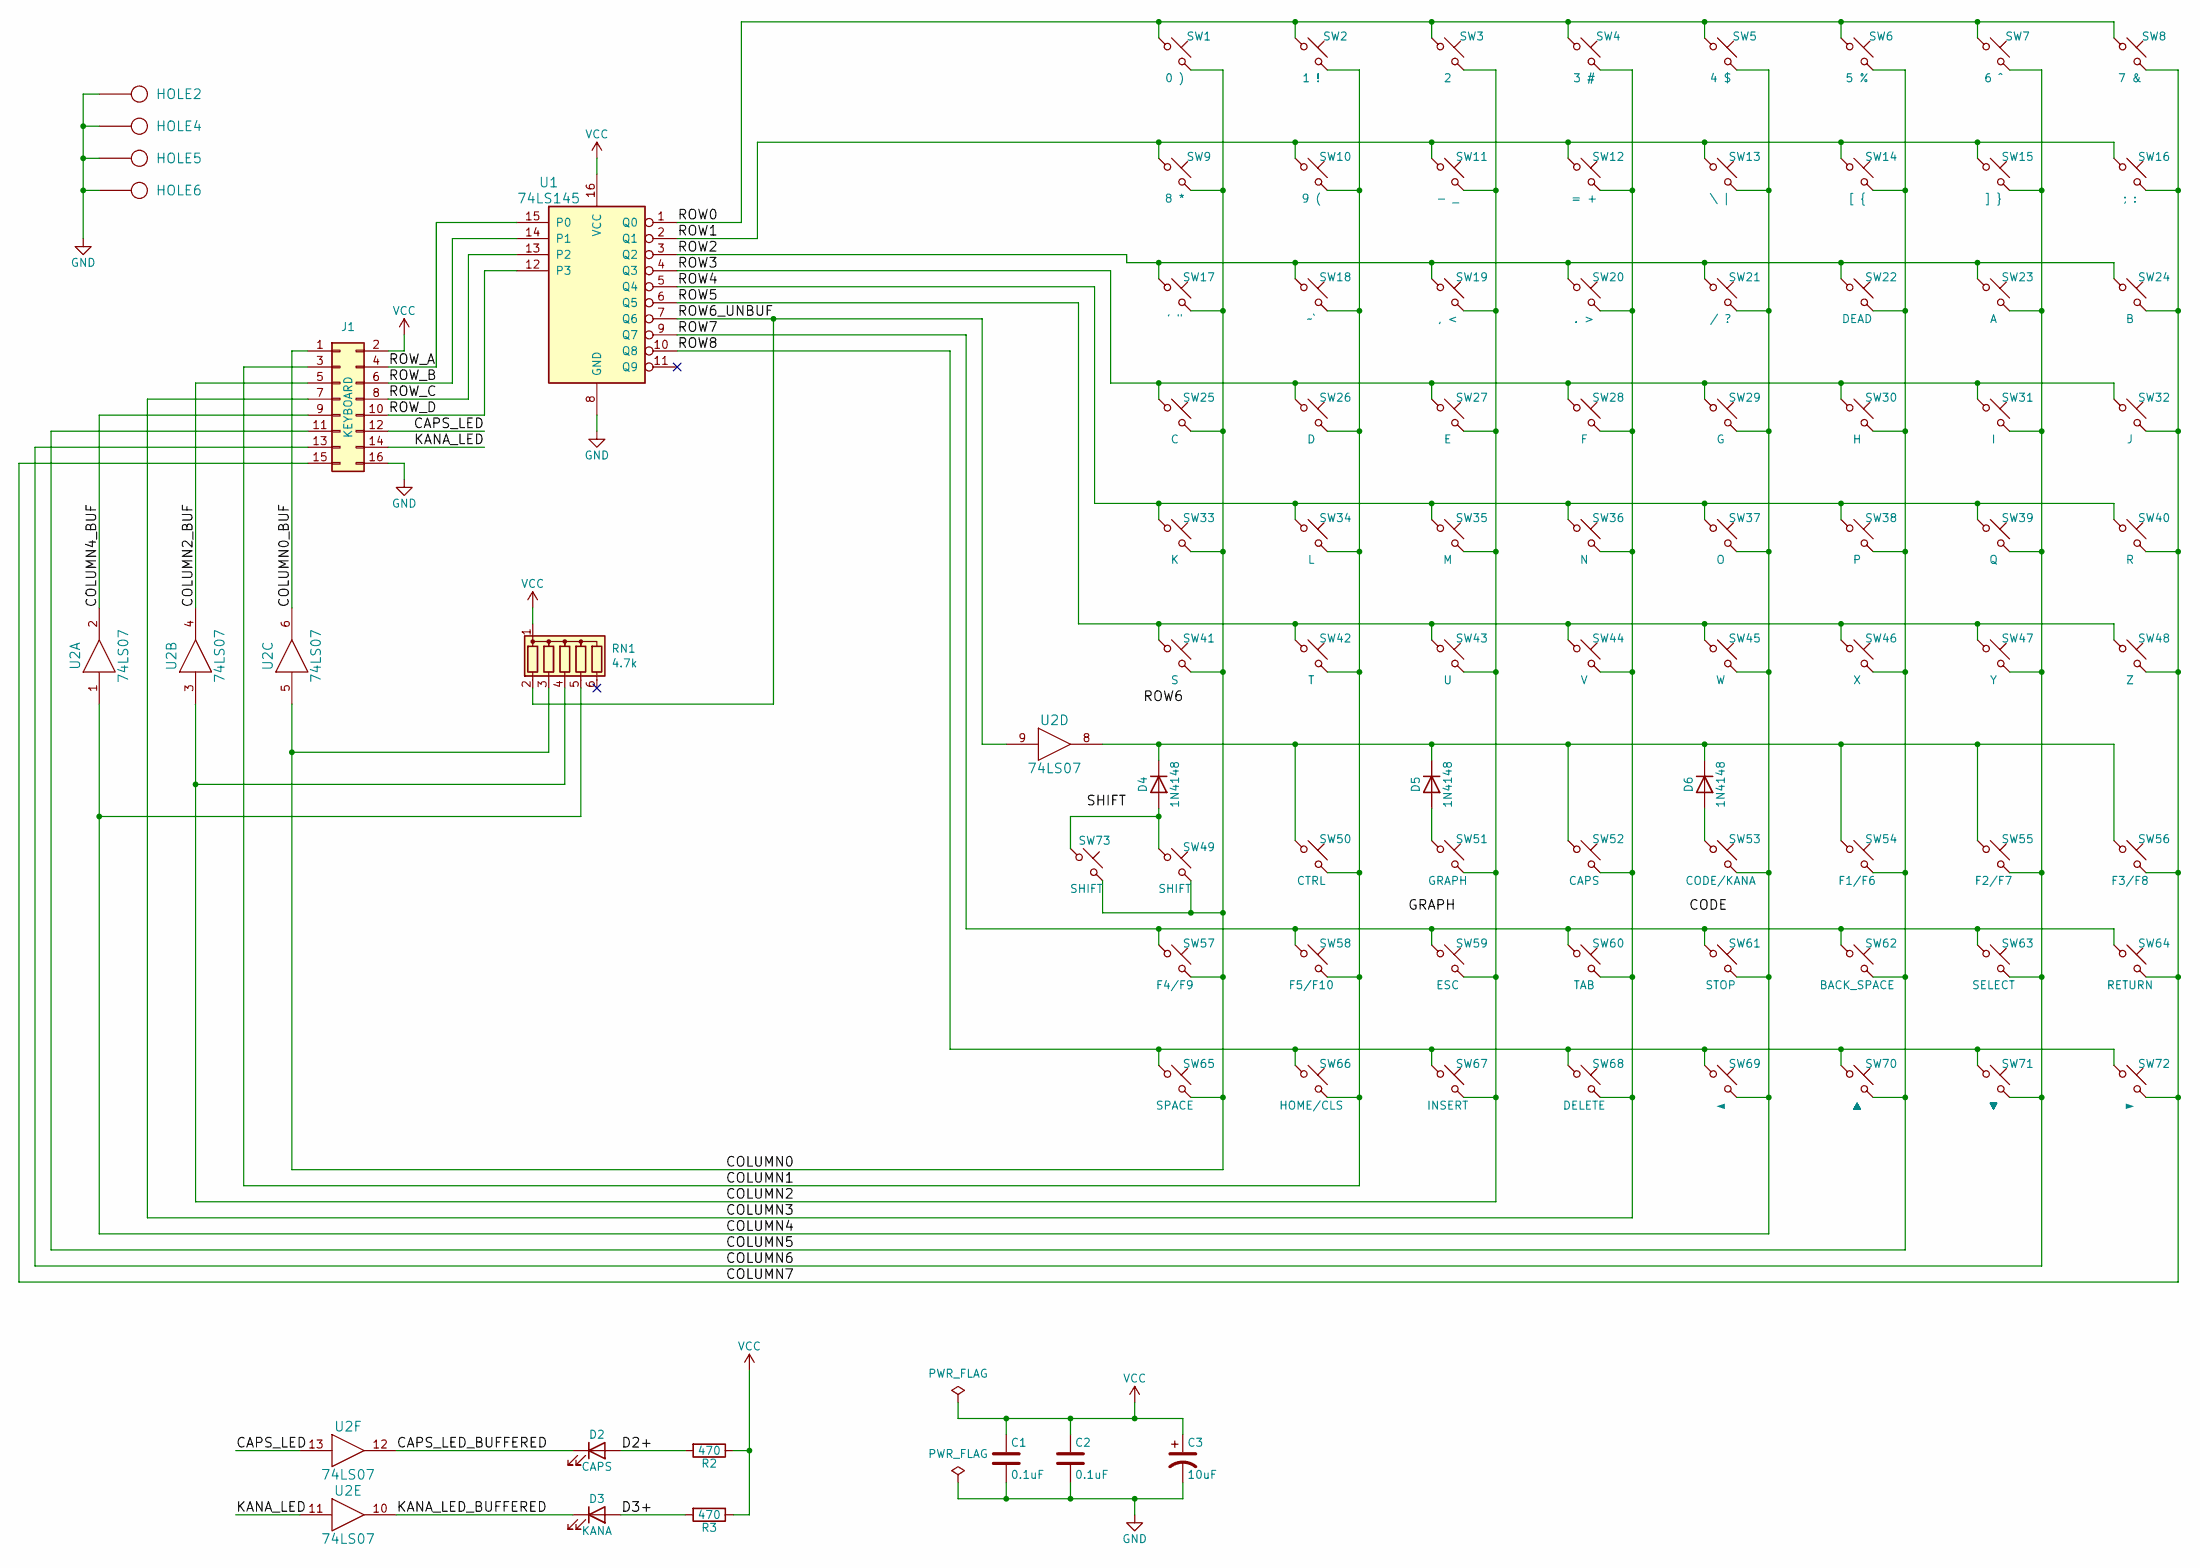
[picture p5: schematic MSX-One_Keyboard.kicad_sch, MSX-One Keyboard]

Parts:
C1, C2: 0.1uF; C_0805_2012Metric_Pad1.18x1.45mm_HandSolder
C3: 10uF; CP_Elec_4x5.7
D2: CAPS; LED_D3.0mm
D3: KANA; LED_D3.0mm
D4, D5, D6: 1N4148; D_DO-35_SOD27_P7.62mm_Horizontal
HOLE2, HOLE4, HOLE5, HOLE6: HOLE; Hole_3mm
J1: KEYBOARD; IDC-Header_2x08_P2.54mm_Horizontal
R2, R3: 470; R_0805_2012Metric_Pad1.20x1.40mm_HandSolder
RN1: 4.7k; Conn_SIL6
SW1: 0 ); SW_PUSH_6mm_H8mm
SW2: 1 !; SW_PUSH_6mm_H8mm
SW3: 2; SW_PUSH_6mm_H8mm
SW4: 3 #; SW_PUSH_6mm_H8mm
SW5: 4 $; SW_PUSH_6mm_H8mm
SW6: 5 %; SW_PUSH_6mm_H8mm
SW7: 6 ^; SW_PUSH_6mm_H8mm
SW8: 7 &; SW_PUSH_6mm_H8mm
SW9: 8 *; SW_PUSH_6mm_H8mm
SW10: 9 (; SW_PUSH_6mm_H8mm
SW11: - _; SW_PUSH_6mm_H8mm
SW12: = +; SW_PUSH_6mm_H8mm
SW13: \ |; SW_PUSH_6mm_H8mm
SW14: [ {; SW_PUSH_6mm_H8mm
SW15: ] }; SW_PUSH_6mm_H8mm
SW16: ; :; SW_PUSH_6mm_H8mm
SW17: ' "; SW_PUSH_6mm_H8mm
SW18: ~`; SW_PUSH_6mm_H8mm
SW19: , <; SW_PUSH_6mm_H8mm
SW20: . >; SW_PUSH_6mm_H8mm
SW21: / ?; SW_PUSH_6mm_H8mm
SW22: DEAD; SW_PUSH_6mm_H8mm
SW23: A; SW_PUSH_6mm_H8mm
SW24: B; SW_PUSH_6mm_H8mm
SW25: C; SW_PUSH_6mm_H8mm
SW26: D; SW_PUSH_6mm_H8mm
SW27: E; SW_PUSH_6mm_H8mm
SW28: F; SW_PUSH_6mm_H8mm
SW29: G; SW_PUSH_6mm_H8mm
SW30: H; SW_PUSH_6mm_H8mm
SW31: I; SW_PUSH_6mm_H8mm
SW32: J; SW_PUSH_6mm_H8mm
SW33: K; SW_PUSH_6mm_H8mm
SW34: L; SW_PUSH_6mm_H8mm
SW35: M; SW_PUSH_6mm_H8mm
SW36: N; SW_PUSH_6mm_H8mm
SW37: O; SW_PUSH_6mm_H8mm
SW38: P; SW_PUSH_6mm_H8mm
SW39: Q; SW_PUSH_6mm_H8mm
SW40: R; SW_PUSH_6mm_H8mm
SW41: S; SW_PUSH_6mm_H8mm
SW42: T; SW_PUSH_6mm_H8mm
SW43: U; SW_PUSH_6mm_H8mm
SW44: V; SW_PUSH_6mm_H8mm
SW45: W; SW_PUSH_6mm_H8mm
SW46: X; SW_PUSH_6mm_H8mm
SW47: Y; SW_PUSH_6mm_H8mm
SW48: Z; SW_PUSH_6mm_H8mm
SW49, SW73: SHIFT; SW_PUSH_6mm_H8mm
SW50: CTRL; SW_PUSH_6mm_H8mm
SW51: GRAPH; SW_PUSH_6mm_H8mm
SW52: CAPS; SW_PUSH_6mm_H8mm
SW53: CODE/KANA; SW_PUSH_6mm_H8mm
SW54: F1/F6; SW_PUSH_6mm_H8mm
SW55: F2/F7; SW_PUSH_6mm_H8mm
SW56: F3/F8; SW_PUSH_6mm_H8mm
SW57: F4/F9; SW_PUSH_6mm_H8mm
SW58: F5/F10; SW_PUSH_6mm_H8mm
SW59: ESC; SW_PUSH_6mm_H8mm
SW60: TAB; SW_PUSH_6mm_H8mm
SW61: STOP; SW_PUSH_6mm_H8mm
SW62: BACK_SPACE; SW_PUSH_6mm_H8mm
SW63: SELECT; SW_PUSH_6mm_H8mm
SW64: RETURN; SW_PUSH_6mm_H8mm
SW65: SPACE; SW_PUSH_6mm_H8mm
SW66: HOME/CLS; SW_PUSH_6mm_H8mm
SW67: INSERT; SW_PUSH_6mm_H8mm
SW68: DELETE; SW_PUSH_6mm_H8mm
SW69: ◄; SW_PUSH_6mm_H8mm
SW70: ▲; SW_PUSH_6mm_H8mm
SW71: ▼; SW_PUSH_6mm_H8mm
SW72: ►; SW_PUSH_6mm_H8mm
U1: 74LS145; SOIC-16_3.9x9.9mm_P1.27mm
U2: 74LS07; SOIC-14_3.9x8.7mm_P1.27mm

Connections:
/CAPS_LED: J1.12, U2.13
/CAPS_LED_BUFFERED: D2.1 (K), U2.12
/COLUMN0: RN1.3 (R2), SW1.2, SW9.2, SW17.2, SW25.2, SW33.2, SW41.2, SW49.2, SW57.2, SW65.2, SW73.2, U2.5
/COLUMN0_BUF: J1.1, U2.6
/COLUMN1: J1.3, SW2.2, SW10.2, SW18.2, SW26.2, SW34.2, SW42.2, SW50.2, SW58.2, SW66.2
/COLUMN2: RN1.4 (R3), SW3.2, SW11.2, SW19.2, SW27.2, SW35.2, SW43.2, SW51.2, SW59.2, SW67.2, U2.3
/COLUMN2_BUF: J1.5, U2.4
/COLUMN3: J1.7, SW4.2, SW12.2, SW20.2, SW28.2, SW36.2, SW44.2, SW52.2, SW60.2, SW68.2
/COLUMN4: RN1.5 (R4), SW5.2, SW13.2, SW21.2, SW29.2, SW37.2, SW45.2, SW53.2, SW61.2, SW69.2, U2.1
/COLUMN4_BUF: J1.9, U2.2
/COLUMN5: J1.11, SW6.2, SW14.2, SW22.2, SW30.2, SW38.2, SW46.2, SW54.2, SW62.2, SW70.2
/COLUMN6: J1.13, SW7.2, SW15.2, SW23.2, SW31.2, SW39.2, SW47.2, SW55.2, SW63.2, SW71.2
/COLUMN7: J1.15, SW8.2, SW16.2, SW24.2, SW32.2, SW40.2, SW48.2, SW56.2, SW64.2, SW72.2
/D2+: D2.2 (A), R2.2
/D3+: D3.2 (A), R3.2
/KANA_LED: J1.14, U2.11
/KANA_LED_BUFFERED: D3.1 (K), U2.10
/ROW0: SW1.1, SW2.1, SW3.1, SW4.1, SW5.1, SW6.1, SW7.1, SW8.1, U1.1 (Q0)
/ROW1: SW9.1, SW10.1, SW11.1, SW12.1, SW13.1, SW14.1, SW15.1, SW16.1, U1.2 (Q1)
/ROW2: SW17.1, SW18.1, SW19.1, SW20.1, SW21.1, SW22.1, SW23.1, SW24.1, U1.3 (Q2)
/ROW3: SW25.1, SW26.1, SW27.1, SW28.1, SW29.1, SW30.1, SW31.1, SW32.1, U1.4 (Q3)
/ROW4: SW33.1, SW34.1, SW35.1, SW36.1, SW37.1, SW38.1, SW39.1, SW40.1, U1.5 (Q4)
/ROW5: SW41.1, SW42.1, SW43.1, SW44.1, SW45.1, SW46.1, SW47.1, SW48.1, U1.6 (Q5)
/ROW6_UNBUF: RN1.2 (R1), U1.7 (Q6), U2.9
/ROW7: SW57.1, SW58.1, SW59.1, SW60.1, SW61.1, SW62.1, SW63.1, SW64.1, U1.9 (Q7)
/ROW8: SW65.1, SW66.1, SW67.1, SW68.1, SW69.1, SW70.1, SW71.1, SW72.1, U1.10 (Q8)
/ROW_A: J1.4, U1.15 (P0)
/ROW_B: J1.6, U1.14 (P1)
/ROW_C: J1.8, U1.13 (P2)
/ROW_D: J1.10, U1.12 (P3)
GND: C1.2, C2.2, C3.2, HOLE2.1, HOLE4.1, HOLE5.1, HOLE6.1, J1.16, U1.8 (GND), U2.7 (GND)
unnamed: D4.1 (K), D5.1 (K), D6.1 (K), SW50.1, SW52.1, SW54.1, SW55.1, SW56.1, U2.8
unnamed: D4.2 (A), SW49.1, SW73.1
unnamed: D5.2 (A), SW51.1
unnamed: D6.2 (A), SW53.1
VCC: C1.1, C2.1, C3.1, J1.2, R2.1, R3.1, RN1.1 (common), U1.16 (VCC), U2.14 (VCC)

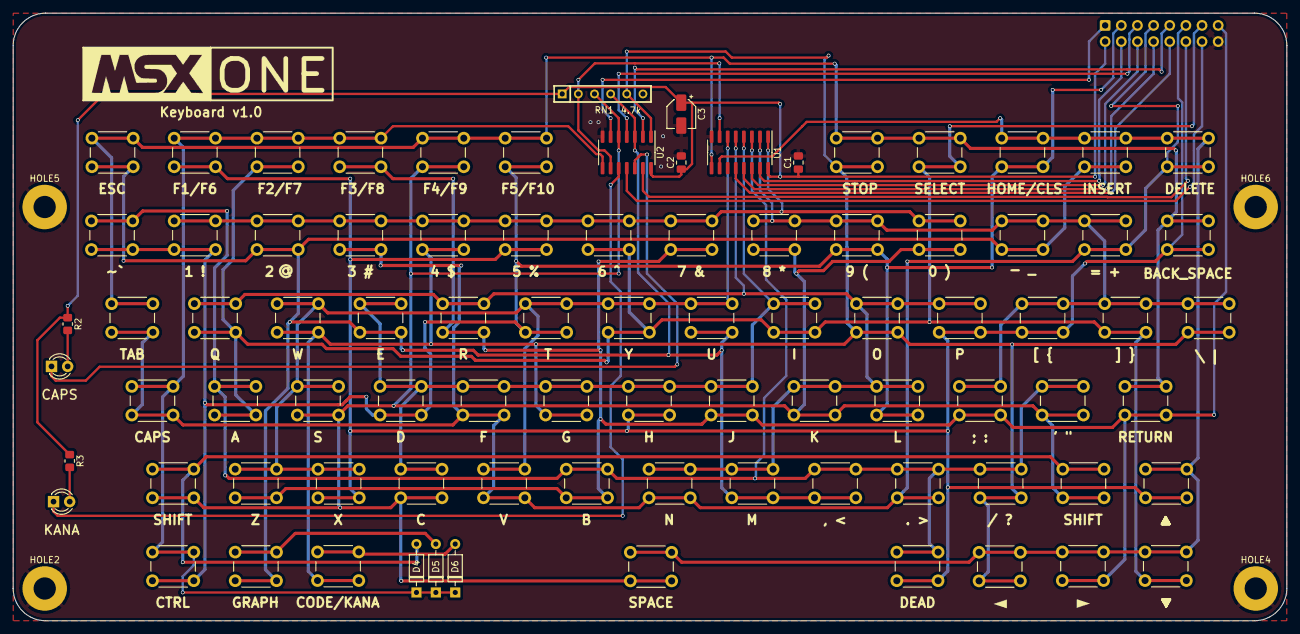
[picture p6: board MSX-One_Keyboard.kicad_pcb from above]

Board: 2 copper layers, 200.3 x 95.6 mm, 91 parts (1 on the bottom side), 36 nets.

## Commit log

2025-02-15 Initial Upload
    Initial upload of project to GitHub.
    [MSX-ONE.csv, MSX-ONE.kicad_sch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]
2025-02-15 MAX701 Information
    Provided info on the MAX701 circuit.
2025-02-17 Update Build_Notes.md
    Added partial BOM
2025-02-18 BOM Update
    BOM Update with minor change to PCB for parts availability.
    [MSX-ONE.kicad_sch, power.kicad_sch]
